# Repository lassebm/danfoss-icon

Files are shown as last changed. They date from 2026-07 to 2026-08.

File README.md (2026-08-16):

# Danfoss Icon → Home Assistant (ESPHome)

An **ESPHome drop-in replacement for the Danfoss Icon App Module (088U1101)**. A small ESP32
node plugs into the **App** port on the Icon controller, speaks the controller's
native wired protocol directly, and exposes every room to **Home Assistant** — **no Danfoss cloud,
no account, no internet dependency**.

## How it works

```text
┌─────────────┐          ┌──────────────────┐          ┌────────────────┐
│ Thermostats │<────────>│ Icon controller  │<════════>│ ESP32 node     │
│ (per room)  │  sub-GHz │ 088U1141         │  RS-485  │ (this project) │
└─────────────┘          │ owns all state   │          │ replaces the   │
                         └──────────────────┘          │ App Module     │
                                                       └───────┬────────┘
                                               Wi-Fi / Thread  │
                                                               ▼
                                                        Home Assistant
```

The Icon controller owns all room state (it gathers temperatures and setpoints from the thermostats
over its own sub-GHz mesh). The real App Module is just a **client** that polls the controller for
that state and pushes user changes back. This project does exactly the same thing: it polls the
controller over the RS-485 link, mirrors each room into an ESPHome `climate` entity, and writes
changes back when you adjust something in Home Assistant. It reaches Home Assistant over the
native ESPHome API on whatever connectivity the ESP32 provides — **Wi-Fi** on most boards, or
**Thread/802.15.4** on the radios that support it.

Because the controller is a **passive responder** — it answers valid requests and otherwise runs
completely standalone — adding this node is **low-risk**: the heating system keeps working with
or without it, and there is no pairing or seeding step. At boot the node simply starts polling —
and keeps every room in **manual mode**, so Home Assistant owns the setpoint and room mode (the
controller's built-in weekly schedule is not used).

## Features

- **Per-room `climate` entity** — current temperature, target setpoint, mode, and action
- **Home / Away / Sleep presets** — the controller's native room modes, each with its own setpoint;
  plus a hub-level **All Rooms Mode** selector that sets every room at once
- **Setpoint writes** from Home Assistant, range-clamped to each room's configured limits
- **Long-term statistics** — per-room Room Temperature and Setpoint sensors, since Home Assistant
  keeps long-term history for sensors but not for climate entities
- **Floor-heating aware** — tracks the room's regulation sensor (air / floor / dual) per room
- **Per-room diagnostics** — battery level, thermostat model & firmware, assigned actuator output
  channels, and fault (e.g. thermostat missing, floor-sensor short / disconnected)
- **Per-controller diagnostics** — firmware / hardware / software versions and fault (e.g. radio
  module missing, output error, a linked controller missing); the primary also reports serial and
  link status
- **Fault rollup** — a Home Assistant "problem" alarm on every room and controller, ready for area
  cards and automations
- **Multi-controller** — a primary plus up to two linked secondary controllers (45 rooms total)
- **Home Assistant sub-devices** — each room can group as its own device, area-assignable
- **Auto-discovery helper** — a button that logs a ready-to-paste config block for your system

## Hardware at a glance

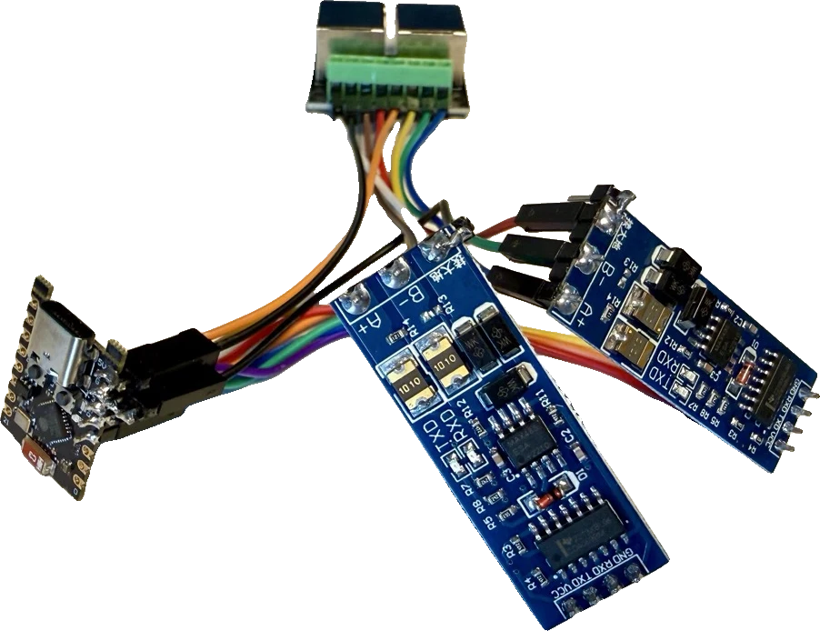
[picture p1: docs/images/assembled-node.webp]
An assembled node — an ESP32-C3 wired to two RS-485 transceiver modules and an RJ45 breakout


- An **ESP32-C3** dev board (any ESP32 with a spare hardware UART works)
- **Two** half-duplex auto-direction RS-485 transceiver modules (used as a full-duplex pair)
- An RJ45 breakout + patch cable to the controller's **App** port

Full bill of materials, pinout, wiring, and power-safety notes: **[docs/HARDWARE.md](docs/HARDWARE.md)**.

## Quick start

1. Build the hardware — **[docs/HARDWARE.md](docs/HARDWARE.md)**
2. Flash and configure ESPHome — **[docs/INSTALL.md](docs/INSTALL.md)**
3. The rooms appear in Home Assistant as climate entities

## Compatibility

Works with the **Danfoss Icon** controller (**088U1141**) that has the **App** port
(where the App Module plugs in). This project replaces the **App Module
(088U1101)** only — the separate **Zigbee Module (088U1130)** is unrelated and out of scope.

> This is **not** the newer "Icon 2" generation. It targets the original Icon controller with the
> **App** port.

## How it was reverse-engineered

The protocol was worked out from the author's own hardware — Danfoss publishes no protocol spec:

- **Traced the PCB** — from datasheets and copper tracing, mapped the RS-485 transceiver, the
  MCU's UART pins, the SPI flash, and the bootloader test points — the groundwork for both the
  capture tap and the firmware dump.
- **Captured the link** — tapped the App Module's UART (the clean TTL side of its RS-485
  transceiver, carrying the controller ↔ App Module traffic) with a logic analyzer and decoded the
  frames (sync, length, CRC-16/MODBUS, the read/write command set).
- **Decompiled the Danfoss Icon app** — it speaks the same attribute model as the wire, so it
  mapped the numeric attribute IDs to human-readable names and, just as usefully, told the story of
  *which* attributes actually matter and how they're encoded — temperatures, setpoints, modes,
  battery, schedules, fault codes — focusing the effort on the relevant handful rather than the
  full attribute space.
- **Dumped the firmware** — read the App Module's CC3200 image out over its UART ROM bootloader,
  and recovered the controller's own firmware from the App Module's flash, where it's staged to
  OTA-update the controller.
- **Confirmed it in Ghidra** — analysed both firmware images to pin down the attribute table,
  value sizes, topology, and fault-bit encodings, then cross-checked everything against the live
  captures.
- **Cross-referenced Danfoss's published Zigbee API** — Danfoss's separate Zigbee Module exposes the
  same underlying attributes onto a Zigbee mesh, and its published API documentation gave
  authoritative names for the status and fault codes (the decoded fault text comes straight from its
  room/system status-code tables) and confirmed the attribute meanings.

The reverse-engineering tooling, firmware dumps, and notes are kept locally and aren't part of
this repository.

## Documentation

| Doc | What |
| --- | --- |
| **[docs/HARDWARE.md](docs/HARDWARE.md)** | Bill of materials, RJ45 pinout, wiring, and power safety |
| **[docs/INSTALL.md](docs/INSTALL.md)** | Flashing, configuration, bring-up, and Home Assistant |
| **[docs/PROTOCOL.md](docs/PROTOCOL.md)** | The wire protocol, for the curious or for contributors |
| **[enclosure/](enclosure/)** | A parametric, 3D-printable enclosure — the author's build, ready to adapt |

## Safety & disclaimer

- This project is the result of **reverse-engineering hardware the author owns**. It is **not
  affiliated with, authorized by, or endorsed by Danfoss**. "Danfoss" and "Icon" are trademarks
  of their respective owners, used here only to describe compatibility.
- You connect this at your own risk. Wiring it incorrectly can damage your controller or the
  node. Read **[docs/HARDWARE.md](docs/HARDWARE.md)** — especially the power-safety section —
  before connecting anything.
- The node only **reads** state and **writes** in-range setpoints/limits. It never initiates the
  firmware-update commands the original App Module uses, and it cannot flash the controller.
- Provided **as-is, without warranty of any kind**. See [LICENSE](LICENSE).

## AI usage

AI was used extensively across this project — to help work through the protocol and to write the
ESPHome component, the host tests, and this documentation. None of it is guesswork: everything is
grounded in the reverse-engineering described above (see
[How it was reverse-engineered](#how-it-was-reverse-engineered)) and validated against real
hardware.

## License

[MIT](LICENSE).

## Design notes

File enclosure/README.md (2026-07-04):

# Enclosure

A parametric, 3D-printable enclosure for the ESP32 node (see
[../docs/HARDWARE.md](../docs/HARDWARE.md)).

<table align="center"><tr>
  <td align="center" width="50%">
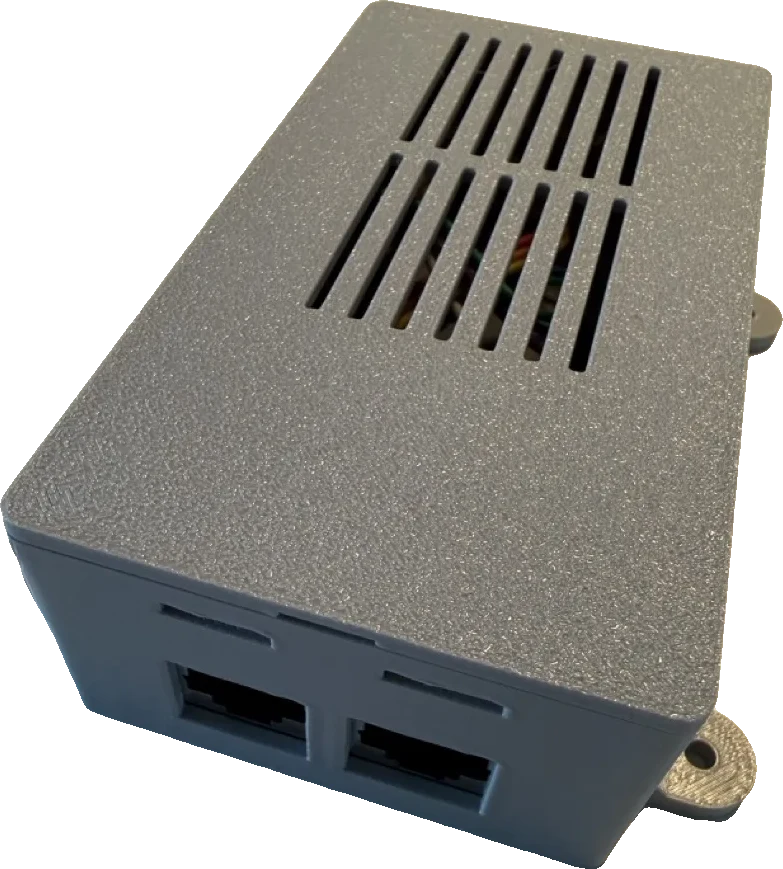
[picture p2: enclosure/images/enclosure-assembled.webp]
The printed enclosure closed, showing the lid vent grille, the front RJ45 jack windows, and a mounting ear
    <br>
    <em>The printed enclosure, closed — lid vent grille on top, RJ45 windows on the front, mounting ears on the sides.</em>
  </td>
  <td align="center" width="50%">
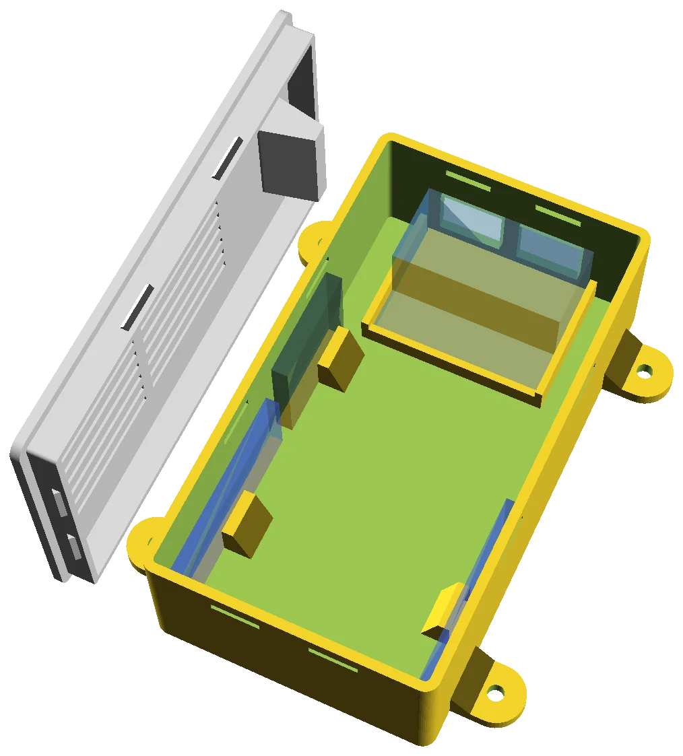
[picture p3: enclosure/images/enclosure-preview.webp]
OpenSCAD render of the enclosure: the open base with translucent board placeholders inside, and the lid shown alongside
    <br>
    <em>How the parts sit inside (OpenSCAD render): the translucent boards are placeholders; the lid is drawn to the side to show its vent grille and RJ45 hold-down tab.</em>
  </td>
</tr></table>

> **This is the author's specific build, shared as a reference.** The model
> ([`enclosure.scad`](enclosure.scad)) is **fully parametric** — [export the STLs](#render--export)
> and print as-is if you used the same parts, or treat it as a starting point and update the
> measurements so it re-fits itself to yours.

Houses the ESP32-C3 Super Mini, both RS-485 transceiver modules, and the double RJ45 breakout,
with a **snap-fit lid** and an **RJ45 jack window**.

The three PCBs **stand on edge leaning against the long side walls** — the ESP32-C3 and one RS-485
along one wall (end-to-end), the other RS-485 along the opposite wall — pinned by small retaining
tabs (and steadied by the cable bundle) rather than full card guides; their connectors face the
central channel. There is **no USB-C
cutout** — open the lid to flash. Ventilation is a fine slot grille **in the lid** over the central
channel (heat rises out, PCBs stay out of sight).

The RJ45 breakout drops into a pocket (front wall + side ribs + a back rib); a hold-down rib on the
lid underside clamps its top edge when the lid closes, so no cable tie or fasteners are needed.

<table align="center"><tr>
  <td align="center">
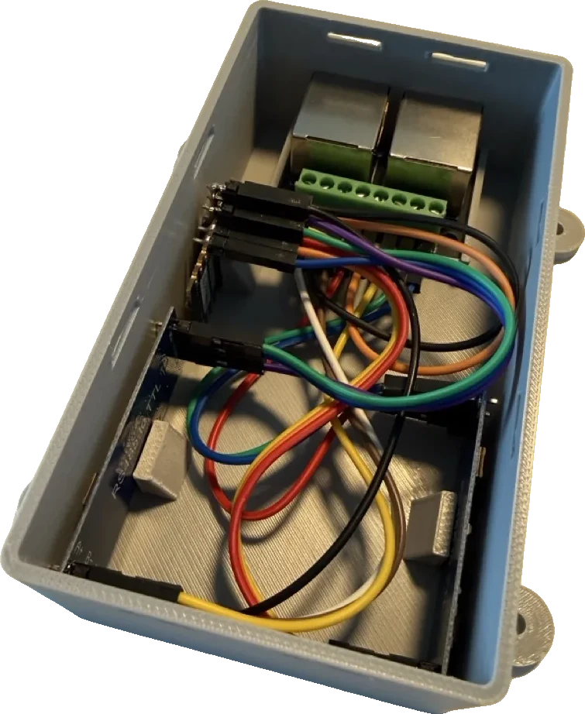
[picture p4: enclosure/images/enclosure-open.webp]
The open base with the real boards installed: PCBs on edge against the long walls, the RJ45 breakout in its front pocket, and the wiring bundle in the central channel
    <br>
    <em>The real build, lid off — boards on edge against the long walls, RJ45 breakout in its front pocket, cable bundle down the central channel.</em>
  </td>
  <td align="center">
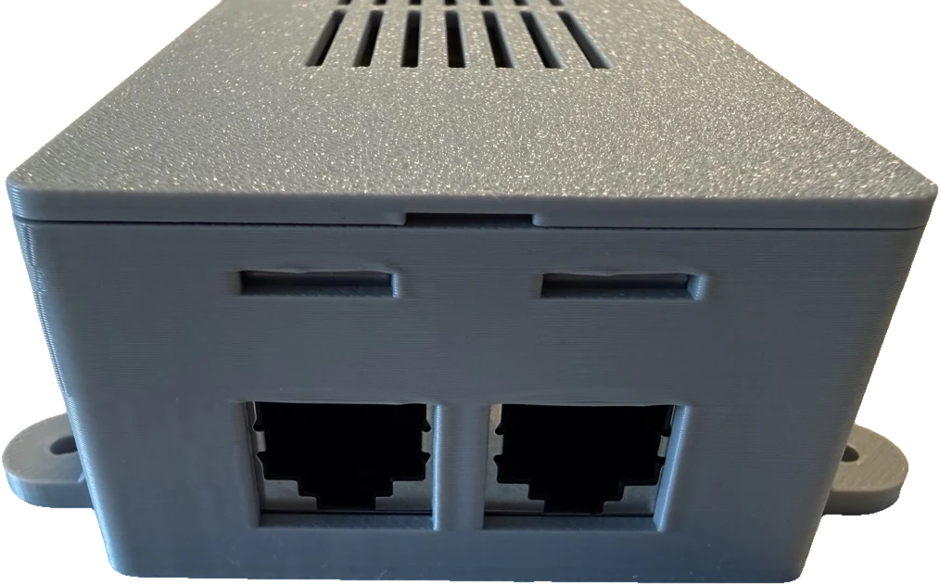
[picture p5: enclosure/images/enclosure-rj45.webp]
Front of the closed enclosure showing the two RJ45 jack windows and the snap-slot openings above them
    <br>
    <em>Front face: the two RJ45 jack windows (and the snap slots above), bridged over during printing.</em>
  </td>
</tr></table>

Four external **mounting ears** at the base (two per long side) take M3 screws for flush surface
mounting; disable with `mount_ears = false`.

## Before you print: measure

Defaults are typical values for the common versions of these boards, **not your exact parts.**
Update every value marked `// MEASURE` in `enclosure.scad`, especially:

- ESP32-C3 & RS-485: **long edge** (runs along the wall, Y), **short edge** (= standing height),
  PCB thickness
- `conn_clear` — how far the header + seated dupont connector + wire bend stick out from one PCB
  face (~20 mm here). Two boards face inward from opposite walls, so this drives the enclosure **width**
  (`inner_x = 2 × (wall_slack + board_t_eff + conn_clear) + mid_gap`).
- RJ45 breakout: board L×W (`rj_l`/`rj_w`), the jack **window** W×H, plus `rj_jack_d` (how far
  the jack housing reaches in from the wall) and `rj_h` (floor to top of the housing) — the lid
  hold-down tab lands on the housing top using these two.

The interior footprint and height are **derived** from these, so the box resizes itself to fit.
The enclosure comes out long and narrow: length = RJ45 zone + (ESP32 + RS-485) end-to-end.

## Adapt it for your build

Different boards, a single full-duplex transceiver, extra ventilation, a USB-C cutout, a DIN-rail
clip — the model is meant to be changed. Two ways in:

- **By hand:** open [`enclosure.scad`](enclosure.scad) in OpenSCAD, edit the named variables at the top
  (start with everything marked `// MEASURE`), press F5 to preview, then re-export (below).
- **With AI:** the whole model is a single, commented, plain-text `.scad` file — a good fit for an
  AI coding assistant. Paste `enclosure.scad` in (or point a tool like Claude Code at this folder),
  describe your parts and what you want changed ("I'm using a DevKitM-1 and one SN65HVD71
  transceiver; add a USB-C cutout on the back wall"), and iterate on the variables and geometry.
  Always render and eyeball the result — and dry-fit a print — before trusting it; AI gets
  dimensions and clearances wrong.

## Render / export

```sh
# Preview with translucent board + connector placeholders (OpenSCAD GUI, F5)
openscad enclosure.scad

# Export the two print parts
openscad -o base.stl -D 'part="base";' enclosure.scad
openscad -o lid.stl  -D 'part="lid";'  enclosure.scad
```

`part` can be `"preview"` (default), `"base"`, `"lid"`, or `"both"`.

## Printing notes

- **Orientation:** print both parts flat (base floor-down, lid top-down), normally no supports.
  The front-wall openings print as **bridges** (top edge anchored both sides): the RJ45 windows are
  split by `rj_win_gap` into two ~14 mm spans, and the snap slots are ~10 mm — both bridge cleanly
  on most printers with part cooling. If yours sags on them, add supports for the **base only**
  (the scars land inside the windows, hidden by the jack). The lid snap teeth are sloped, so the
  lid itself needs no supports.
- **Material:** PLA or PETG, 3 perimeters, 20% infill.
- **Snap fit is printer-dependent.** Print the **lid first** and test the click. Too tight →
  raise `fit_clear` or lower `snap_depth`; too loose → the reverse. Teeth are placed on all
  four walls — `snap_n_short` / `snap_n_long` set how many per short/long wall (long-side teeth
  keep the long lid edges from gapping). A tiny **channel under the lid's jack-end edge**
  (`lid_grip` / `grip_w` / `grip_l` / `grip_d`), hidden from the top, lets a nail catch under the
  lip to lift it off.
- **Boards a loose/tight fit?** small retaining tabs pin each board against its wall — set the
  standoff with `esp_tab_off` / `rs_tab_off` (distance wall → tab) and size with `tab_w/t/h`; toggle
  with `board_tabs`. For the central cable room widen `mid_gap`, or tune `wall_slack` for the wall
  gap.
- **Ventilation:** `vent_w` / `vent_gap` set the lid slot pitch; set `lid_vents = false` to seal it up.
- **Mounting ears:** `mount_ears` toggles them; `mount_hole_d` sets the screw size, `mount_ext` /
  `mount_ear_w` / `mount_inset` the shape and spacing, `mount_gusset` the brace height.

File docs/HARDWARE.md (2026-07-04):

# Hardware

This describes how to build the ESP32 node that plugs into the **App** port on the
Icon controller and speaks its protocol. The link is **full-duplex RS-485 at 115200 8-N-1** — the controller drives one
differential pair, the node drives the other.

<p align="center">
  An assembled node — an ESP32-C3 wired to two RS-485 transceiver modules and an RJ45 breakout<br>
  <em>Overview of an assembled node — see the pinout and wiring tables below for the exact connections.</em>
</p>

## Bill of materials

| Qty | Part | Notes |
| --- | --- | --- |
| 1 | **ESP32-C3** dev board | e.g. ESP32-C3 Super Mini or DevKitM-1. Any ESP32 with a spare hardware UART works; the example config targets an ESP32-C3. |
| 2 | **Half-duplex auto-direction RS-485 transceiver module** | The common "TTL ↔ RS-485, automatic direction control" breakout (no DE/RE enable pin to drive). **Two** of them form a full-duplex link — one receives, one transmits. |
| 1 | **RJ45 breakout / keystone + patch cable** | To tap the controller's **App** port. A punch-down keystone or a cut patch cable both work. |
| — | Jumper wires | Module ↔ ESP32 ↔ RJ45. |

> **Why two half-duplex modules instead of one full-duplex transceiver?** The link is genuinely
> full-duplex (two separate pairs, both can carry data at once). The cheap auto-direction modules
> are half-duplex, so one module is dedicated to the receive pair and the other to the transmit
> pair. This mirrors what the original App Module does with a single full-duplex transceiver, but
> with parts you can buy for a couple of dollars.
>
> **A single full-duplex transceiver works too** (e.g. SN65HVD71, MAX3491) — it has separate
> driver and receiver, so it exposes one TX (`DI`) and one RX (`RO`) pin to the MCU and needs **no
> direction control** (the auto-direction logic on the cheap modules only exists to arbitrate a
> shared half-duplex line, which full-duplex doesn't have). Wire `DI`←GPIO3, `RO`→GPIO4, the
> receive pair from RJ45 1/2 and the drive pair to RJ45 3/6. It's the tidier option if you can
> source one; the two-module approach is just cheaper and more commonly on hand.

## RJ45 controller-port pinout

The controller's RJ45 carries two differential pairs plus power and ground:

| Pin | Signal | Pair |
| --- | --- | --- |
| 1 | controller → node **+** (A) | orange pair |
| 2 | controller → node **−** (B) | orange pair |
| 3 | node → controller **+** (Y) | green pair |
| 6 | node → controller **−** (Z) | green pair |
| 4 | **+5 V** | power |
| 7 | **+5 V** | power (duplicate of pin 4) |
| 5 | **GND** | ground |
| 8 | **GND** | ground (duplicate of pin 5) |

- **Pins 1 & 2** (orange) = controller → node. The node *receives* on this pair.
- **Pins 3 & 6** (green) = node → controller. The node *transmits* on this pair.
- **Pins 4 & 7 are the same +5 V net; pins 5 & 8 are the same GND net** — each rail is duplicated
  across two conductors. At your breakout, **tie 4 ↔ 7 together and 5 ↔ 8 together**, then run a
  single +5 V and single GND on to the board so the load is shared across both conductors.

## Wiring

Two half-duplex auto-direction modules, used as a full-duplex pair:

| Module | RS-485 side | TTL side |
| --- | --- | --- |
| **RX module** (receive) | A ← RJ45 **pin 1**, B ← RJ45 **pin 2** | RXD → ESP32 **GPIO4** (UART RX); TXD unconnected (it never drives) |
| **TX module** (transmit) | A → RJ45 **pin 3**, B → RJ45 **pin 6** | TXD ← ESP32 **GPIO3** (UART TX); RXD unconnected |

Power and ground (see the bridging note above):

- RJ45 **+5 V (bridged pins 4 & 7)** → ESP32-C3 **`5V` / `VIN`** pin
- RJ45 **GND (bridged pins 5 & 8)** → ESP32-C3 **`GND`**, **and** to the `GND` of *both* transceiver
  modules — everything must share a common ground.
- The transceiver modules run from the ESP32's **3.3 V** rail; their logic levels then match the
  ESP32's 3.3 V GPIOs.

```text
  Signal and power (full pin detail is in the tables above):

  RJ45 pins 1,2  ──>  RX module  ──RXD─>  ESP32 GPIO4 (RX)
  RJ45 pins 3,6  <──  TX module  <─TXD──  ESP32 GPIO3 (TX)
  RJ45 pins 4,7  ──(+5 V, bridged)─────>  ESP32 5V / VIN
  RJ45 pins 5,8  ──(GND, bridged)──────>  ESP32 GND  (common)

  ESP32 3V3 + GND  ──>  powers both transceiver modules
```

The UART pins (GPIO3 TX / GPIO4 RX) are configurable in YAML; the ESP32-C3 routes UART through its
GPIO matrix, so any free pins work. Avoid the strapping pins (GPIO2, 8, 9) and the USB pins (18, 19).

## ⚠️ Power safety — do **not** back-feed +5 V and USB at the same time

On most ESP32-C3 dev boards the `5V`/`VIN` header pin is the **same net as USB VBUS** (no
isolation diode). Feeding RJ45 +5 V into `VIN` *while USB is also plugged in* parallels two 5 V
sources and back-feeds one into the other.

- **Bench bring-up (USB plugged in for logs):** leave RJ45 **+5 V (pins 4 & 7) disconnected**.
  Wire only the data pairs (1/2, 3/6) and GND (5/8). USB powers the ESP32-C3 and the modules.
- **Deployment (no USB):** power from RJ45 +5 V → `VIN`, as wired above.
- **Need both live at once:** Schottky-diode-OR the RJ45 +5 V and USB VBUS into `VIN`.

## Notes

- **3.3 V logic** on the transceiver's receive output (`RXD`, or `RO` on a bare chip) is safe for
  the ESP32.
- **Termination/bias** is generally unnecessary for the short cable runs typical here; add
  120 Ω termination across each pair only if you see signal-integrity issues on a long run.

## Enclosure

A parametric, 3D-printable enclosure for the assembled node lives in
**[../enclosure/](../enclosure/)** — it's the author's specific build (ESP32-C3 Super Mini + two
RS-485 modules + double RJ45 breakout), shared as a reference you can re-fit to your own parts.

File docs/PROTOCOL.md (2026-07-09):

# Wire protocol

The link between the Icon controller (088U1141) and the App Module (088U1101) over the RJ45 patch
cable. This is the **"Cumulus"** attribute protocol — the same attribute model the controller, the
original App Module, and the Danfoss cloud all share.

You don't need any of this to *use* the project — it's here for the curious and for contributors.
The implementation lives in [`esphome/components/danfoss_icon/protocol.h`](../esphome/components/danfoss_icon/protocol.h),
with a host-side unit test in `test_protocol.cpp`.

> **Why you'll see "master" elsewhere.** This doc — like the rest of the project (README,
> config, entities) — calls the device the **controller**. Danfoss's own firmware and
> documentation name it the **"master controller"** (and the rails it aggregates **"slave"**), so
> if you dig into the firmware or Danfoss's materials you'll meet *master/slave* — the same
> devices under their lower-level names.

## Roles

On the RJ45 link the **node (App Module) is the initiator** and the **controller is the responder**:

- The node sends **read** and **write** commands; the controller replies to each one.
- The controller never initiates traffic on this link — it owns all room state and simply answers.

> The controller is *also* a poller on a **separate** sub-GHz mesh to the thermostats, using nearly
> identical framing. Don't conflate the two links: on the RJ45 the controller only ever responds.

## Physical layer

- **Full-duplex RS-485**, two differential pairs (see [HARDWARE.md](HARDWARE.md) for pinout).
- **115200 baud, 8-N-1.**

## Transaction model

The link is electrically full-duplex (separate pairs), but the protocol is strictly
request/response: the node keeps **one transaction outstanding** — it sends a command and waits for
the matching `0x0D` (or a timeout) before sending the next. Replies are matched to commands purely
by **order** (there is no index/attribute echo). The controller never sends anything unsolicited,
so the link is treated as up only while replies keep arriving — prolonged silence is the only
"disconnected" signal.

## Frame format

Commands and responses share a 4-byte header (`sync`, `len`, `0x01`, `cmd`), then diverge:

```text
command   01 [len] 01 [cmd] [idx]     [counts] [attr_id …] [value …]  [crc_lo] [crc_hi]
response  01 [len] 01 [cmd] [status]  [value …]                       [crc_lo] [crc_hi]
```

- `sync` (`0x01`) — start of frame.
- `len` — TOTAL frame length in bytes (`sync` … `crc_hi` inclusive). Structural minimum 7 bytes
  (an empty-value response); frames run up to ~61 in practice.
- `0x01` — fixed frame-type byte.
- `cmd` — command byte (see [command set](#command-set)).
- `idx` (command only) — device/room index.
- `status` (response only) — `0x00` = OK; non-zero = rejected (see [response status codes](#response-status-codes)).
- `counts` (command only) — read count in the high nibble ("n2"), write count in the low ("n1").
- `attr_id …` (command only) — (n1 + n2) × uint16, **big-endian**.
- `value …` — the write payload (after the id list), or the value a response returns.
  **Big-endian.**
- `crc_lo crc_hi` — CRC-16/MODBUS (init `0xFFFF`, reflected poly `0xA001`) over every byte before
  the two CRC bytes; **little-endian** on the wire.

## Command set

| Command | Direction | Meaning |
| --- | --- | --- |
| **`0x0C`** | node → controller | **command**: read (uses the `n2` count) or write (uses the `n1` count) |
| **`0x0D`** | controller → node | **response**: `[status=00][value…]`, matched to the command by order |
| `0x30` / `0x32` / `0x34` | node → controller | firmware-update sub-protocol (arm / data block / verify) |

The `0x30`/`0x32`/`0x34` commands are how the *original* App Module flashes the controller's firmware
over this same link. **This project never sends them** — it only reads and writes attributes, and
cannot flash the controller.

## Response status codes

The `status` byte of a `0x0D` reply is `0x00` on success; a non-zero value means the controller
rejected the command. These are the codes it returns on the attribute read/write path:

| Status | Meaning |
| --- | --- |
| `0x00` | OK |
| `0x02` | attribute not found — on a **read** (the controller has no such attribute) |
| `0x03` | attribute not found — on a **write** |
| `0x04` | value **out of range** (failed the attribute's min/max bounds) |
| `0x05` | attribute is **read-only / protected** |
| `0x07` | **length error** — the value is shorter than the attribute's size |

In practice the two you'll see are `0x04` (e.g. a setpoint outside the room's configured
min/max) and `0x05` (writing an identity or diagnostic attribute). The hub logs the decoded reason
on a rejected read/write.

## Read

```text
node → controller:  01 [len] 01 0C [idx] [n2<<4] [attr_id …]
controller → node:  01 [len] 01 0D 00 [value …]

example
node → controller:  01 0a 01 0c 31 10 03 00 35 de      (read room idx 0x31, attr 0x0300)
controller → node:  01 09 01 0d 00 09 8a b3 c2          (value 0x098a = 24.42 °C)
```

A read lists attribute IDs only (the `n2`/read count); the controller returns the value(s) it owns,
matched to the request **by order** (the response carries no attribute echo). Multiple IDs can be
batched into one command — e.g. the boot identity read.

## Write

```text
node → controller:  01 [len] 01 0C [idx] [n1] [attr_id] [value …]

example
node → controller:  01 0c 01 0c 31 01 05 09 08 66 ..crc  (set room 0x31 attr 0x0509 = 0x0866 = 21.50 °C)
```

A write uses the `n1`/primary count. The controller applies it subject to the attribute's
writable flag and its min/max range check — out-of-range writes are rejected, so send in-range
values.

## Device index — system topology

The `idx` byte of a command (shown in the frame layout above) selects which entity it addresses:

| Index | Entity |
| --- | --- |
| `0x00` | global / system identity |
| `0x01–0x03` | controllers (rails) — primary + up to two secondary |
| `0x04–0x30` | actuator outputs |
| **`0x31–0x5D`** | **room thermostats** — Room *n* on controller *c* is `0x31 + (c-1)*15 + (n-1)` |

The **same attribute ID means different things depending on the entity class** — e.g. `0x03F0` is
a room-fault bitmask on a room and a rail/system-fault bitmask on a controller. Always treat an
attribute as the pair (index-class, attribute-id).

## Value encoding

- **Temperatures / setpoints** — `uint16` big-endian, **×100 °C** (`0x08FC` = 23.00, `0x0708` =
  18.00). **`0x8000` = invalid / no-sensor / unconfigured** sentinel.
- **Version strings** — length-prefixed ASCII (`05 '6' '.' '0' '4' 00` → "6.04").
- **`u8`** — enum / flag / percentage. **`u32`** — timestamps / serial-like values.
- **Schedule blocks** (`0x100C–0x1012`, Mon–Sun) — 13-byte records; documented for completeness but
  **not used by this project** (rooms are held in manual mode, so the controller's weekly schedule
  never runs).

Because a response carries no attribute echo, the node slices the reply into values using the
known **byte size of each requested attribute**, in request order. The sizes for the attributes
this component uses are encoded in `protocol.h` (`attr_value_size`).

## Bring-up sequence

At boot the node just starts issuing reads and the controller answers. The original App Module's
startup sequence (which this project mirrors as needed) is:

1. Read a one-time identity bulk from idx 0 (revision, serial, software version, etc.).
2. Sweep per-slot identity across the controllers (versions, presence).
3. Settle into steady-state attribute polling across all rooms and outputs.

## Attributes used

The complete set this project reads and writes, grouped by entity class. The same numeric id means
different things per class, so read each table as `(class, attribute)`.

**Room** (idx `0x31`–`0x5D`):

| Attribute | Meaning | Notes |
| --- | --- | --- |
| `0x0300` | room (air) temperature | ×100 °C |
| `0x0304` | floor temperature | ×100 °C |
| `0x030A` | floor-sensor / regulation mode | 0 Comfort, 1 Floor, 2 Dual |
| `0x030F` | thermostat battery | percent; `0xFE` = low, `0xFF` = wired |
| `0x03F0` | error code | 16-bit fault bitmask (room faults) |
| `0x0507` / `0x0508` | setpoint min / max | per-room limits, **writable** |
| `0x0509` | home setpoint | **writable** — the Home climate-preset target |
| `0x050A` | away setpoint | **writable** — the Away climate-preset target |
| `0x050B` | sleep setpoint | **writable** — the Sleep climate-preset target |
| `0x050C` / `0x050D` | floor temp min / max | floor clamp limits, **writable** |
| `0x007F` | device firmware version | length-prefixed ASCII |
| `0x0080` | device descriptor | carries the thermostat product id |
| `0x100A` | room mode | **writable** — 0 Home, 1 Away, 2 Sleep; the HA climate preset. Selects which preset setpoint regulates |
| `0x100B` | room control | 0 manual, non-zero = running a schedule; always held at 0 so HA owns the mode/setpoint (the controller's own schedule is not used) |
| `0x1013` | heating/cooling state | drives the climate **action** (heating / idle) |
| `0x1020` / `0x1021` / `0x1022` | output-group bitmaps (slow / medium / fast) | union = which actuator channels serve the room |

**Controller / rail** (idx `0x01`–`0x03`) and **global** (idx `0x00`):

| Attribute | Meaning | Notes |
| --- | --- | --- |
| `0x0015` | revision | hardware version in bytes `[0:1]`, software version in `[2:3]` |
| `0x007F` | firmware version | length-prefixed ASCII |
| `0x03F0` | error code | 16-bit fault bitmask (rail/system faults) |
| `0x0016` | serial number | `u32`, global idx 0 — describes the primary controller |

Outputs (idx `0x04`–`0x30`) are actuator channels on the wire but aren't polled — a room's served
channels come from its own output-group bitmaps (`0x1020`/`0x1021`/`0x1022` above).

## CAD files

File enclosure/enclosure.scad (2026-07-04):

// Danfoss Icon node — 3D-printable enclosure
// ===========================================
// Parametric enclosure for the ESP32-C3 node described in docs/HARDWARE.md:
//   - 1x ESP32-C3 Super Mini
//   - 2x half-duplex RS-485 auto-direction transceiver modules
//   - 1x double RJ45 breakout, mounted so its sockets face out a wall cutout
//
// The three PCBs (ESP32 + 2x RS-485) stand on edge against the long side walls
// (ESP32 + one RS-485 on the RIGHT, the other RS-485 on the LEFT, opposite it),
// pinned to the walls by small retaining tabs (no card guides); connectors face
// the central channel. Snap-fit lid, no USB cutout (open the lid to flash), a vent
// grille in the lid, and four external ears at the base for flush wall mounting.
//
// HOW TO USE
//   1. Measure YOUR parts with calipers and update the MEASUREMENTS block below.
//      Values marked  // MEASURE  are real-world dimensions to verify.
//   2. Set `part` and render (F5 preview / F6 render, export STL).
//   3. Snap fit is printer-dependent — print the lid first and tune snap_depth /
//      fit_clear.
//
// Coordinates: origin at inner-floor front-left corner. +X right, +Y back (away
// from the RJ45 wall), +Z up. RJ45 breakout sits against the FRONT (-Y) wall;
// the standing boards run their long edge along Y against the +/-X side walls.

// ------------------------------------------------------------------
// WHAT TO RENDER
// ------------------------------------------------------------------
part = "preview";   // "preview" | "base" | "lid" | "both"
show_boards = true;     // in "preview", draw translucent board placeholders
show_connectors = true; // in "preview", also draw the header+dupont clearance boxes

// ------------------------------------------------------------------
// MEASUREMENTS  (edit these — see docs/HARDWARE.md for the parts)
// ------------------------------------------------------------------

// -- ESP32-C3 Super Mini (stands on its long edge) -----------------
esp_l      = 24.8;  // MEASURE long edge  -> horizontal (along X)
esp_stand  = 23.4;  // MEASURE short edge -> vertical standing height

// -- RS-485 transceiver module (x2, stand on their long edge) ------
rs_l       = 42.8;  // MEASURE long edge  -> horizontal (along X)
rs_stand   = 16.8;  // MEASURE short edge -> vertical standing height

// Clearance on the connector side of each standing board for the pin header +
// seated dupont connector + wire bend. Two boards face inward from opposite
// walls, so this drives the enclosure WIDTH (see inner_x below).
conn_clear = 20.0;  // MEASURE header+connector+wire depth on one face

// -- Double RJ45 breakout (lies against the front wall) ------------
rj_l       = 37.4;  // MEASURE board length (along the front wall, X)
rj_w       = 28.2;  // MEASURE board depth  (whole board into the enclosure, Y)
rj_jack_d  = 18.4;  // MEASURE jack-housing depth from the front wall (Y)
rj_h       = 16.8;  // MEASURE floor to top of the jack housing (Z) — lid tab lands here
rj_win_w   = 31.9;  // MEASURE cutout width for the two jack faces (both jacks)
rj_win_h   = 12.0;  // MEASURE cutout height for the jack faces
rj_win_z   = 3.65;  // MEASURE jack-window bottom above the floor
rj_win_gap = 4.0;   // MEASURE gap between the two jacks -> center divider so the
                    // top prints as two short bridges (0 = one wide window)

// ------------------------------------------------------------------
// ENCLOSURE / FIT PARAMETERS
// ------------------------------------------------------------------
wall_t      = 2.0;  // wall thickness
floor_h     = 2.0;  // floor thickness
lid_h       = 2.0;  // lid plate thickness
corner_r    = 3.0;  // outer corner radius (vertical edges)

fit_clear = 0.4; // slack for the lid fit and RJ45 width (loosen if the lid is tight)
top_clear = 5.5; // air gap above the tallest board, under the lid (sets wall height)

// RJ45 pocket ribs (the standing boards use no guides)
rj_rib_h    = 6.0;  // side-rib height (seats the board against the front wall)
rj_rib_t    = 1.6;  // rib wall thickness
front_gap   = 3.0;  // gap between RJ45 breakout and the first standing board

// RJ45 retention: drop-in pocket (front wall + side ribs + back rib) plus a
// hold-down tab on the lid underside that presses the top of the JACK HOUSING
// (the rigid part, within rj_jack_d of the wall) when the lid is closed.
rj_backrib_h     = 4.0;  // height of the rib behind the RJ45 board (stops push-in;
                         // kept low to clear the dupont cables in the screw terminals)
rj_hold_len_frac = 0.6;  // lid hold-down tab length as a fraction of the board length
rj_hold_tip      = 4.0;  // tab thickness at the contact face (along Y)
rj_hold_root     = 9.0;  // tab thickness where it meets the lid (tapers to the tip)
rj_hold_pos_frac = 0.6;  // tab centre as a fraction of the jack-housing depth (from wall)
rj_hold_load     = -0.3; // minimal downward preload on the jack (nominal; print stackup
                         // adds a little). Light touch to settle the jack -> only a tiny lid gap.

// Snap-fit lid
lip_h        = 6.0;  // depth the lid plug lip reaches into the enclosure
lip_t        = 1.6;  // thickness of the plug lip
snap_depth   = 0.9;  // how far the snap tooth protrudes / engages (deeper = firmer/harder to open)
snap_h       = 1.8;  // tooth height; ~2x snap_depth keeps both faces near 45 deg
snap_z       = 4.0;  // tooth center below the top rim
snap_l       = 10.0; // length of each snap tooth along the wall
snap_n_short = 2;    // teeth per SHORT wall (front/back)
snap_n_long  = 2;    // teeth per LONG wall (sides) — hold the long lid edges down

// Ventilation — a fine slot grille in the lid over the central cable channel
// (heat rises out, keeps the PCBs out of sight/dust). Set lid_vents=false to seal it up.
lid_vents   = true;
vent_w      = 1.6;  // slot width (thin)
vent_gap    = 3.0;  // gap between slots (and crossbar width between rows)
vent_rows   = 2;    // split each lid slot along its length into N (stiffens the ribs)
vent_frac   = 0.6;  // fraction of the span covered by the slot band

// Wall-mount ears — flat flanges at the base with a screw hole, for flush
// surface mounting. Two per long side (+/-X), inset from the ends (4 total).
mount_ears    = true;
mount_ext     = 7.0;   // how far the ear reaches out past the wall (X)
mount_ear_w   = 12.0;  // ear width along the wall (Y)
mount_ear_h   = 3.0;   // ear/flange thickness (Z)
mount_hole_d  = 3.4;   // screw clearance hole (M3 -> 3.4)
mount_inset   = 13.0;  // ear centre distance in from each end (Y)
mount_gusset  = 7.0;   // gusset height up the wall for strength (0 = none)

// Board retaining tabs — small posts on the centre-facing side of each standing
// board that pin it against its wall (the tab lands on the board's back face; the
// header pins/wires pass beyond it toward the centre). Offset = wall -> tab face.
board_tabs  = true;
esp_tab_off = 4.1;  // ESP32:  tab distance from the RIGHT wall
rs_tab_off  = 3.4;  // RS-485: tab distance from its wall
tab_w       = 10.0; // tab width along the board (Y)
tab_h       = 8.0;  // retaining-face height from the floor (Z)
tab_top     = 2.5;  // flat top length toward the centre (before the brace slopes down)
tab_base    = 6.0;  // total buttress length toward the centre at the floor (braces the tab)

// Lid grip — a tiny channel in the UNDERSIDE of the jack-end edge, running inward
// from the outer edge, so a nail slides under the lip and catches to lift the lid.
lid_grip = true;
grip_w   = 8.0;   // channel width along the edge (X)
grip_l   = wall_t + fit_clear/2;  // reach in from the outer edge (Y) — ends right
                  // against the lip's outer face, without running over/past the lip
grip_d   = 0.7;   // channel depth up into the lid underside (Z; shallow keeps more
                  // plate above to take the upward nail force)

$fn = 48;

// ==================================================================
// LAYOUT
// ==================================================================
// The three PCBs stand on edge, pinned to the walls by small retaining tabs:
//   RIGHT (+X) long wall: ESP32 then one RS-485, end-to-end along Y
//   LEFT  (-X) long wall: the other RS-485, directly opposite the right one
// Each board's face is parallel to its wall; connectors face the central channel.
// The RJ45 breakout sits in its pocket against the FRONT (-Y) wall.

board_t_eff   = 2.5;  // per-board width allowance for inner_x (standoff set by *_tab_off)
row_gap       = 3.0;  // gap between the ESP32 and RS-485 sharing the RIGHT wall (Y)
end_margin    = 2.0;  // clear space behind the last board (Y)
wall_slack    = 0.5;  // gap between a board face and the wall it leans on (X)
mid_gap       = 10.0; // clear gap in the centre between the two connector fields
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

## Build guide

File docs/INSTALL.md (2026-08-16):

# Installation

Get the node flashed, configured, and talking to Home Assistant.

## Prerequisites

- The **hardware built and wired** per [HARDWARE.md](HARDWARE.md).
- Either the **ESPHome Device Builder app** (add-on) in Home Assistant (the usual route for HA
  users), or the **ESPHome CLI** if you prefer a terminal.

## 1. Add the component

This is published as an ESPHome **external component** — no checkout required. Your device config
pulls it straight from this repo:

```yaml
external_components:
  - source: github://lassebm/danfoss-icon@main
    components: [danfoss_icon]
```

The bundled [`esphome/danfoss-icon.yaml`](../esphome/danfoss-icon.yaml) is a complete, working
example to copy from. It defaults to a **local** source (`type: local`, `path: components`) so it
builds directly inside a clone of this repo; to deploy from the published component, switch to the
`github://` source it keeps commented at the top of its `external_components:` block (the same one
shown above).

## 2. Create the device and set Wi-Fi

### Home Assistant — ESPHome Device Builder app (recommended)

1. Open the **ESPHome** dashboard → **＋ New Device**, name it (e.g. `danfoss-icon`).
2. **Edit** its YAML and paste in the `external_components`, `uart`, and `danfoss_icon` blocks
   (copy from the example, then edit your rooms — see [step 3](#3-configure-your-rooms)).
3. Set Wi-Fi in the dashboard's **Secrets** editor (top-right **⋮ → Secrets**): add `wifi_ssid`
   and `wifi_password` once, and every device's `!secret` references resolve against it.

### ESPHome CLI

The config uses `!secret`, so create a secrets file next to it:

```bash
cd esphome
cp secrets.yaml.example secrets.yaml   # then edit in your Wi-Fi credentials
```

`secrets.yaml` is gitignored, so your credentials never get committed.

## 3. Configure your rooms

The one part you must edit is the room list. Each room has a `number` (1–15 on its controller)
and a `name`:

```yaml
danfoss_icon:
  id: icon
  uart_id: controller_uart
  rooms:
    - number: 1
      name: "Kitchen"
    - number: 2
      name: "Bedroom"
```

Don't know your room numbers? Flash with a couple of placeholder rooms, then press the
**"Discover Config"** button — it logs a ready-to-paste `rooms:` block for your actual system
(see [step 5](#5-bring-up--discovery)).

**UART.** The bundled config already sets the UART to match [HARDWARE.md](HARDWARE.md); you only
need to touch it if you wired different pins. The 8-N-1 framing is ESPHome's default, so the
block is just:

```yaml
uart:
  id: controller_uart
  tx_pin: GPIO3
  rx_pin: GPIO4
  baud_rate: 115200
```

**Rooms as Home Assistant devices (optional).** To give each room its own area-assignable HA
device, declare the devices once and reference them per room with `device_id`:

```yaml
esphome:
  name: danfoss-icon
  devices:
    - id: dev_kitchen
      name: "Kitchen"

danfoss_icon:
  rooms:
    - number: 1
      name: "Kitchen"
      device_id: dev_kitchen
```

The **primary controller is this node itself** — its firmware / hardware / software versions,
serial, link status, and fault appear automatically on the node's device. Add
`secondary_controllers:` only if you have additional controllers linked to the primary.

### Configuration reference

#### `danfoss_icon:` (hub)

| Option | Default | Meaning |
| --- | --- | --- |
| `uart_id` | — | the UART configured above (required) |
| `poll_interval` | `2s` | how often to refresh room state |
| `reply_timeout` | `500ms` | how long to wait for a response before moving on |
| `connection_timeout` | `15s` | controller silence before the link reports disconnected |
| `all_rooms_mode` | `true` | create the hub-level **All Rooms Mode** select (Home/Away/Sleep/Off across every room) |
| `discover_button` | `true` | create the "Discover Config" helper button |
| `firmware`, `hardware_version`, `software_version`, `serial` | `true` | which primary-controller identity sensors to create |
| `fault` | `true` | primary-controller Fault text **and** Problem alarm |
| `rooms` | `[]` | your rooms (see below) |
| `secondary_controllers` | `[]` | additional linked controllers (see below) |

The primary controller's entities live on this node device. The **Connection** (link health) sensor
is always created; the toggles above hide the rest if you don't want them.

#### Per room

| Option | Default | Meaning |
| --- | --- | --- |
| `number` | — | room number 1–15 on its controller (required) |
| `name` | — | room name (required) |
| `controller` | `1` | rail position: 1 = primary (this node), 2/3 = a secondary |
| `device_id` | — | optional HA sub-device to group the room's entities under |
| `floor` | `false` | room has a floor sensor → adds floor temp, floor mode, floor min/max |
| `room_temperature` | `true` | air-temperature sensor |
| `setpoint` | `true` | setpoint sensor |
| `setpoint_limits` | `true` | expose editable Setpoint Min/Max number entities |
| `battery`, `model`, `firmware`, `outputs` | `true` | which diagnostic entities to create |
| `fault` | `true` | room Fault text **and** Problem alarm |

Room Temperature and Setpoint duplicate what the climate already shows, on purpose: Home Assistant
keeps long-term history for sensors but not for climate entities. Room Temperature is the *air*
reading, which in Floor mode the climate replaces with the floor probe.

#### Per secondary controller (`secondary_controllers:`)

A linked controller at rail position 2 or 3. It has no serial or connection sensor — those are
primary-only.

| Option | Default | Meaning |
| --- | --- | --- |
| `number` | — | rail position: 2 or 3 (required) |
| `name` | — | controller name (required) |
| `device_id` | — | optional HA sub-device to group its entities under |
| `firmware`, `hardware_version`, `software_version` | `true` | which identity sensors to create |
| `fault` | `true` | controller Fault text **and** Problem alarm |

## 4. Install / flash

First flash is over USB. Keep RJ45 **+5 V disconnected** while USB is connected — see the
power-safety note in [HARDWARE.md](HARDWARE.md).

- **App:** click **Install** on the device (plug in over USB for the first flash; later
  updates go over Wi-Fi / OTA).
- **CLI:** `esphome run danfoss-icon.yaml`

## 5. Bring-up & discovery

Watch the logs (**Logs** in the app, or `esphome logs danfoss-icon.yaml`). If wiring and
polarity are right, you'll see the controller's `0x0D` replies decoded with sensible values
(room temperatures, setpoints, …) — that confirms the link works in both directions.

Press the **"Discover Config"** button to log a ready-to-paste `rooms:` block enumerating the
rooms your controller actually reports, then copy it into your config.

## 6. Home Assistant

Home Assistant auto-discovers the node over the native ESPHome API; confirm/add the integration.
Each room shows up as a **climate** entity with **Home / Away / Sleep** presets — each preset has its
own setpoint, and the controller regulates to whichever is selected — plus the diagnostic sensors you
enabled. A hub-level **All Rooms Mode** select (Home / Away / Sleep / Off) also appears on the node
device and switches every room at once. Change a setpoint and confirm it takes effect on the
thermostat — that round-trips a write to the controller.

Every room is kept in manual mode so Home Assistant owns the mode and setpoint; the controller's own
weekly schedule is not used.

## Troubleshooting

- **No `0x0D` replies in the logs.** Check the RS-485 wiring first. The two pairs are
  direction-specific — if you see nothing, try **swapping the A/B (or the pair) connections**;
  reversed polarity is the most common cause. Confirm a common ground between the ESP32, both
  transceiver modules, and the RJ45.
- **Bad-CRC / garbled frames.** Usually noise or a marginal connection on a data pair; check
  the crimp/punch-down and keep the data leads short.
- **Link reports disconnected.** The node infers the link from reply silence — if polls aren't
  being answered, it's the same wiring/polarity check as above.
- **Setpoint write rejected.** The controller range-checks writes; make sure the value is within
  the room's configured Setpoint Min/Max.
- **Don't power from USB and RJ45 +5 V simultaneously** — see the power-safety section in
  [HARDWARE.md](HARDWARE.md).

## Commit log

2026-06-27 Trim transparent margin on the assembled-node photo
2026-06-28 Make polling registration-driven; tidy discovery and diagnostics
    Polling: replace the static per-room/controller poll arrays with
    per-entity registration (add_fast_attr/add_slow_attr). build_poll_list_
    groups registrations by idx and de-dups, fast tier winning over slow, so
    the node polls exactly what the configured entities consume. Model,
    firmware and controller-identity attrs are now polled only when their
    entities are enabled; floor temperature is fast-polled for floor rooms
    (the displayed current temperature in Floor mode) and non-floor rooms no
    longer poll floor attrs.
    Connection: always fast-poll the primary controller revision as a link
    heartbeat, so the Connection sensor stays accu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
2026-07-04 Add parametric 3D-printable enclosure
    A reference enclosure for the assembled node (ESP32-C3 Super Mini + two
    RS-485 modules + double RJ45 breakout): the parametric enclosure.scad, a
    README with print and adapt notes, and photos of the printed result.
    Linked from the root README and HARDWARE.md; exported STLs are gitignored.
    Photos (enclosure + the bare node) are background-removed transparent
    cutouts so they sit cleanly on both light and dark themes.
    [enclosure.scad]
2026-07-09 Add Home/Away/Sleep climate presets and All Rooms Mode select
    Expose the controller's native room modes as Home Assistant climate
    presets Home/Away/Sleep (room mode 0x100A), each backed by its own
    setpoint (0x0509/0x050A/0x050B). The active preset's setpoint is the
    climate target and the slider edits it; OFF parks Home at frost and
    HEAT / selecting Home restore it.
    Add a hub-level "All Rooms Mode" select (Home/Away/Sleep/Off) that sets
    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
2026-08-16 Add per-room Room Temperature and Setpoint sensors
    Home Assistant compiles long-term statistics only for sensor entities carrying a
    state_class, so a climate entity's current and target temperature survive no
    longer than the recorder's short-term retention. Rooms therefore had no lasting
    temperature history unless `floor: true` was set, which was the only path that
    created a standalone air-temp sensor.
    Room Temperature (0x0300) is no longer gated on the floor feature set, and a new
    Setpoint sensor mirrors the climate's target — the setpoint of whichever preset
    (Home/Away/Sleep) is active. Both default on, per-room `room_temperature:` and
    `setpoint:` turn them off.
    Neither adds bus traffi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
